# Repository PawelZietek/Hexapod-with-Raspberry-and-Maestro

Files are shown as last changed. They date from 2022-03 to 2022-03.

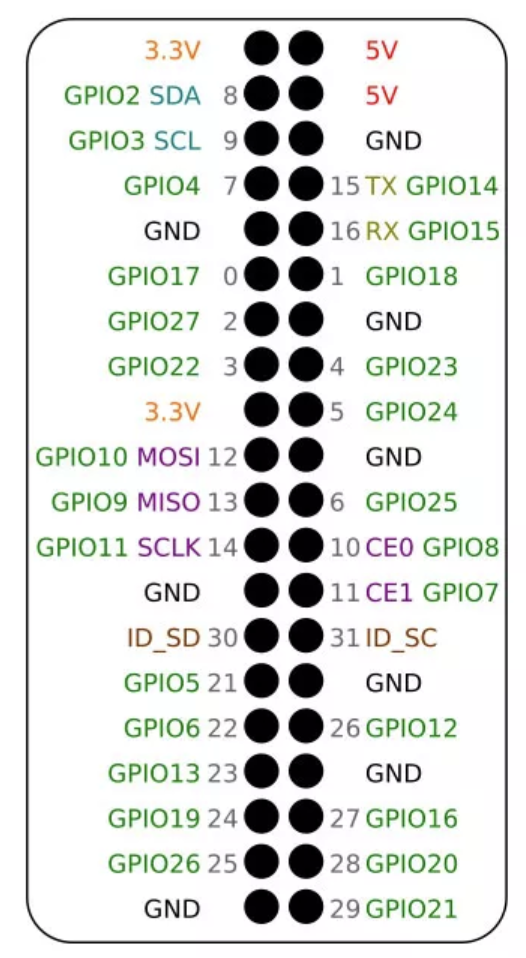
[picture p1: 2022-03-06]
pics, diagrams, videos/pinout.PNG

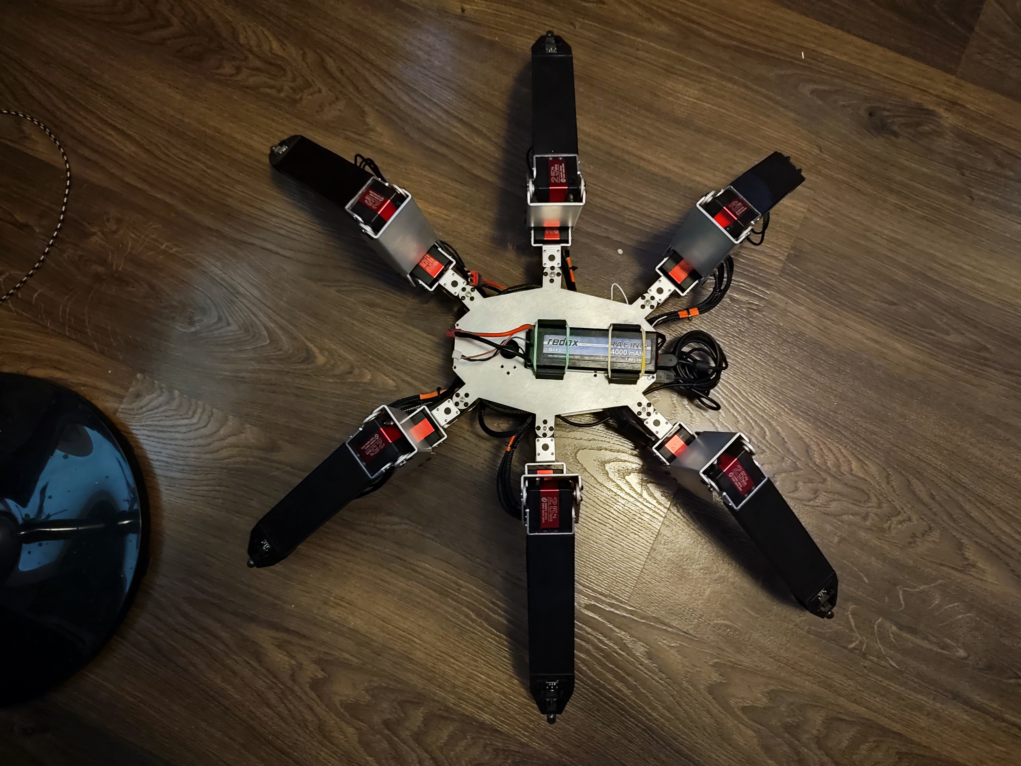
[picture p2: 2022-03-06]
pics, diagrams, videos/Hexapod4.jpg

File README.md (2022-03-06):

Hi, I built a hexapod based on a raspberry pi, pololu maestro 24 channel servo controller, 18x RDS3225 cheap robotics servos, and couple other stuff.
I share all needed files including 3d printed parts and dxf drawing for laser cutting. I also include pictures of all connections I've made.

The electronics you need(with links):
1. Raspberry Pi 4B 2GB - https://botland.store/raspberry-pi-4b-modules-and-kits/14646-raspberry-pi-4-model-b-wifi-dual-band-bluetooth-2gb-ram-15ghz-765756931175.html
2. Pololu Maestro 24ch - https://www.pololu.com/product/1356
3. 18x RDS3225 ROBOTIC servos - its important for servos to be robotic type with shafts on both sides - https://pl.aliexpress.com/item/32907625266.html?gatewayAdapt=glo2pol
4. UBEC 5V 3A - https://www.amazon.com/Adafruit-UBEC-Step-Down-Buck-Converter/dp/B00PLV0VC0
5. 6x microswitches - https://www.amazon.com/FYSETC-Printer-Accessories-Mechanical-Endstops/dp/B07ZCSXNF3
6. 2 cell 7,4V LiPo battery pack with charger
7. xbox 360 controller with usb receiver

Mechanical Parts and tools needed:
1. Screwdrivers, pliers, callipers
2. 3d printer access
3. cutting laser access
4. lots of m3, m4 phillips head screws different lenghts with washers and bolts
5. soldering iron access with wires and other stuff for it<br />

hexapod_project_fusion 1
hexapod_project_fusion 3
hexapod_project_fusion 4
Final models of leg and foot<br />
foot
leg

In the picture below i numbered servos from 0 to 17 and this is order i'm using later in my code.<br />
hexapod_project_fusion 6

Here's how i connected everything with raspberry.<br />
connection

And how swtiches and power are connected to Raspberry GPIO.<br />
gpio connection

My raspberry is using Ubuntu 20.04. Main code is in Python. You will need to instal repositories like xboxdrv, python3, pip, etc.<br />
Hexapod1
Hexapod2
Hexapod3
Hexapod4

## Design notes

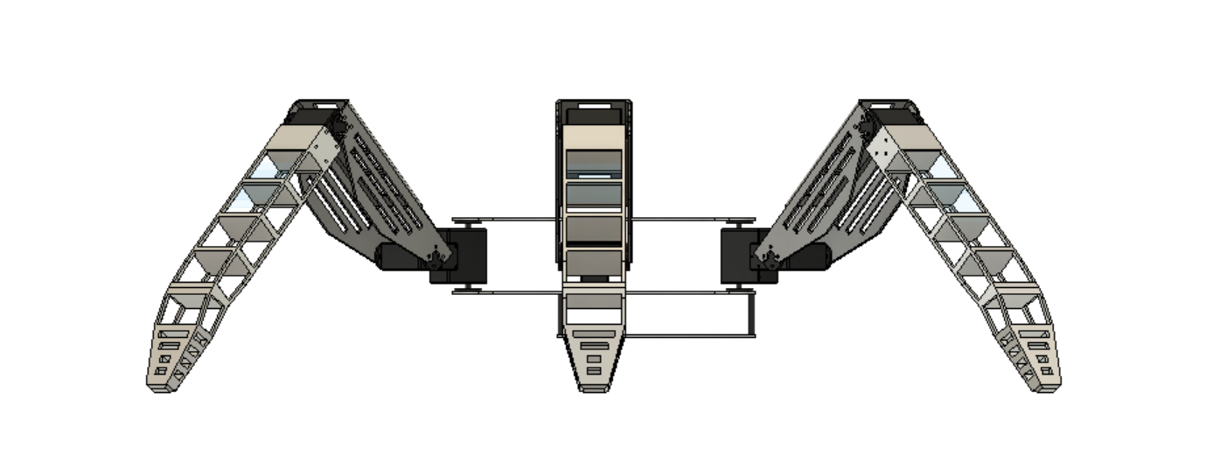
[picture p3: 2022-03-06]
pics, diagrams, videos/hexapod_project_fusion 2.PNG

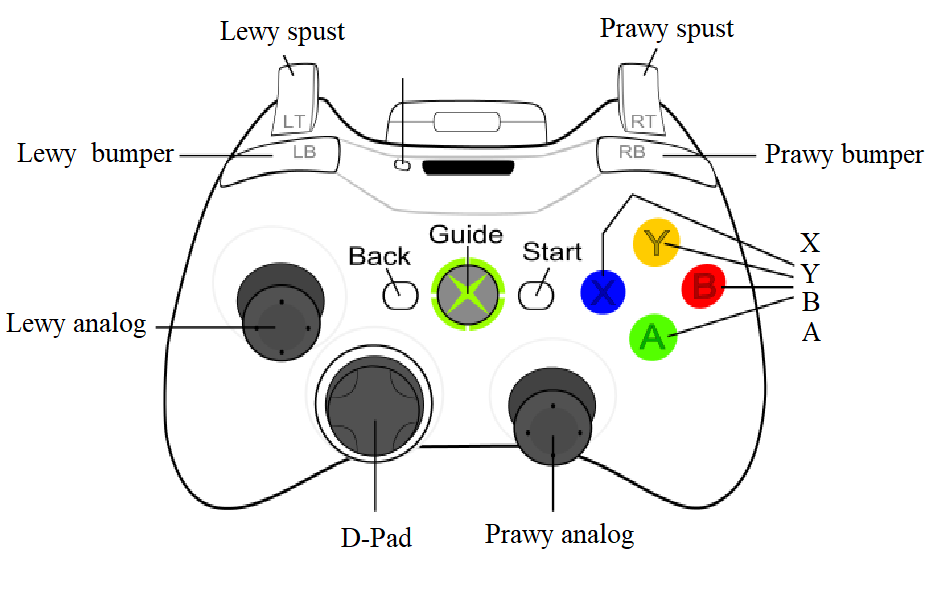
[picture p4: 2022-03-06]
pics, diagrams, videos/360_controller.png

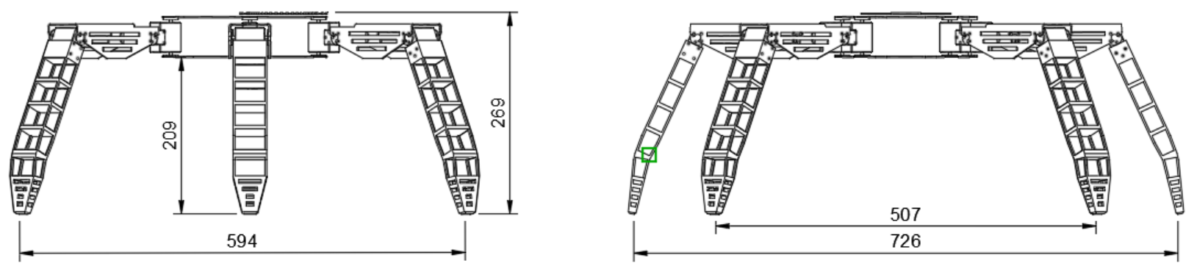
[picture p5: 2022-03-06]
pics, diagrams, videos/hexapod_drawings 2.PNG

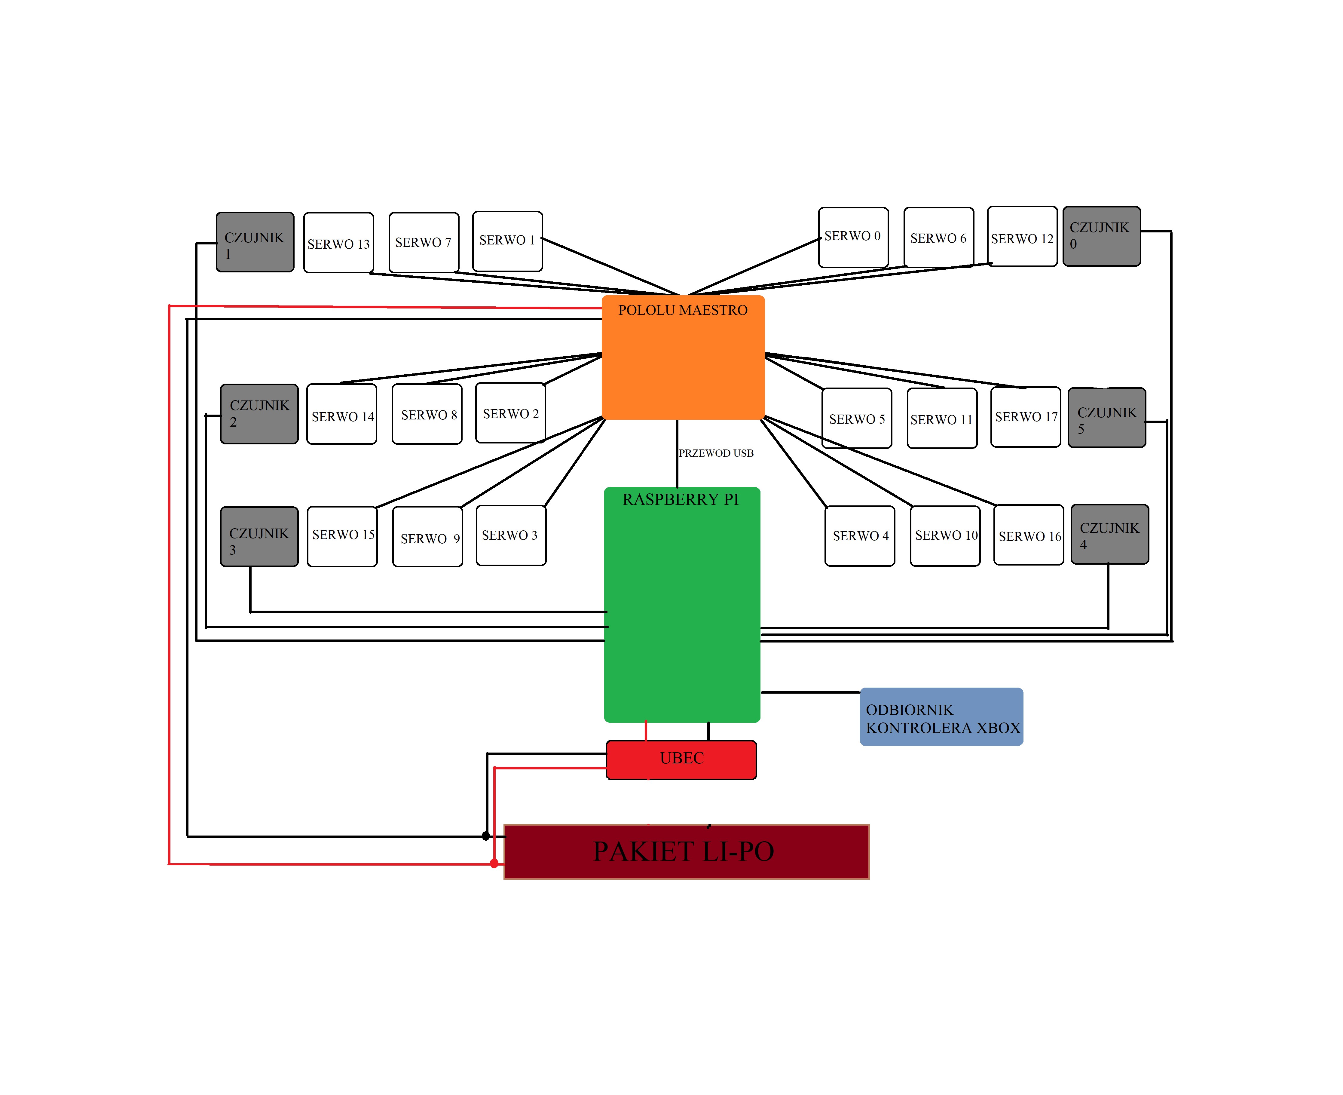
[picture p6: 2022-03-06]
pics, diagrams, videos/connection.png

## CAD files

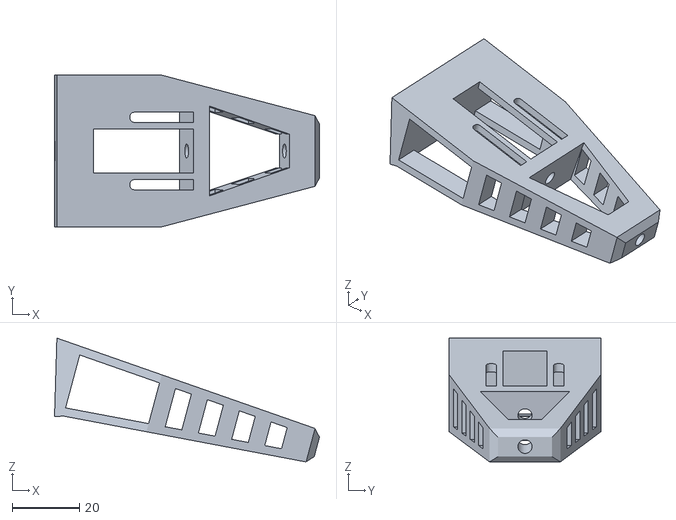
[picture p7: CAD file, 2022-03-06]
STL,dxf/foot.stl
78.6 x 45.0 x 36.7

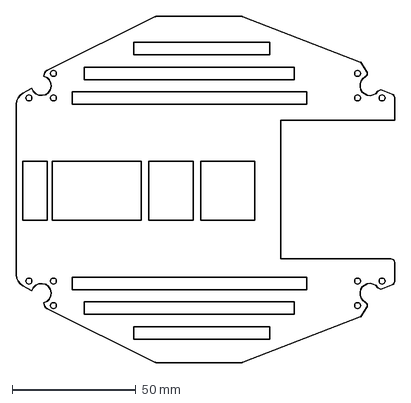
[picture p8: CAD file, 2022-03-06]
STL,dxf/tibia2018.dxf
153.0 x 140.0 mm

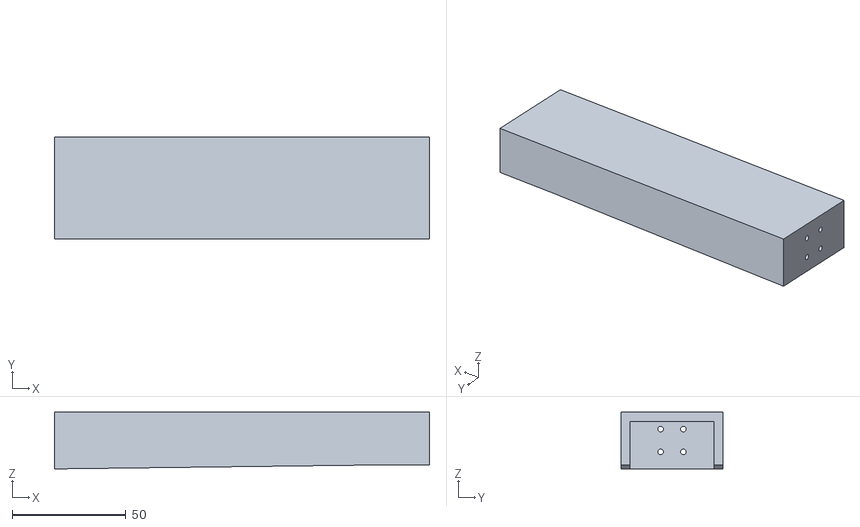
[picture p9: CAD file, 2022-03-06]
STL,dxf/Leg.stl
165.0 x 45.0 x 25.0

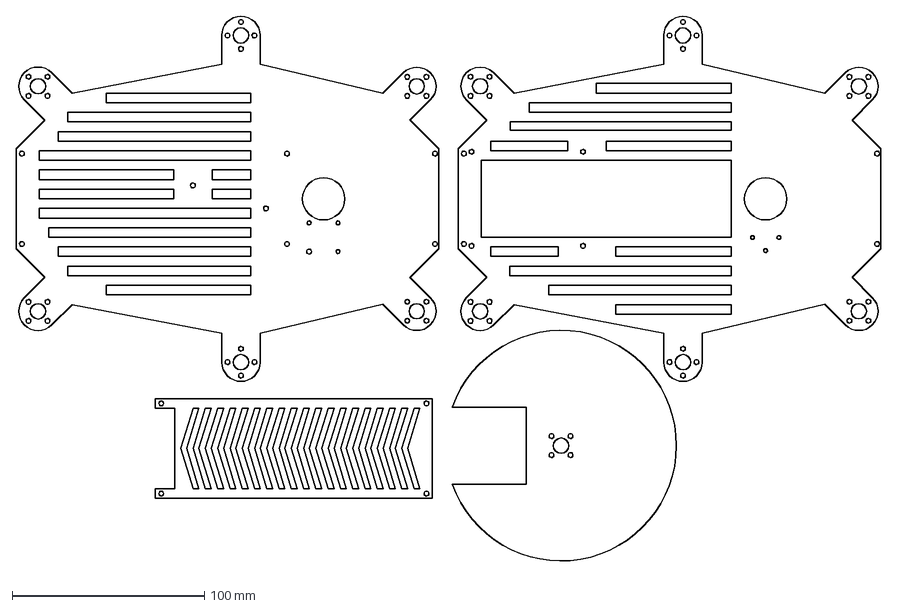
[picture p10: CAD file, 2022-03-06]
STL,dxf/Hexapod V2.dxf
450.0 x 287.5 mm

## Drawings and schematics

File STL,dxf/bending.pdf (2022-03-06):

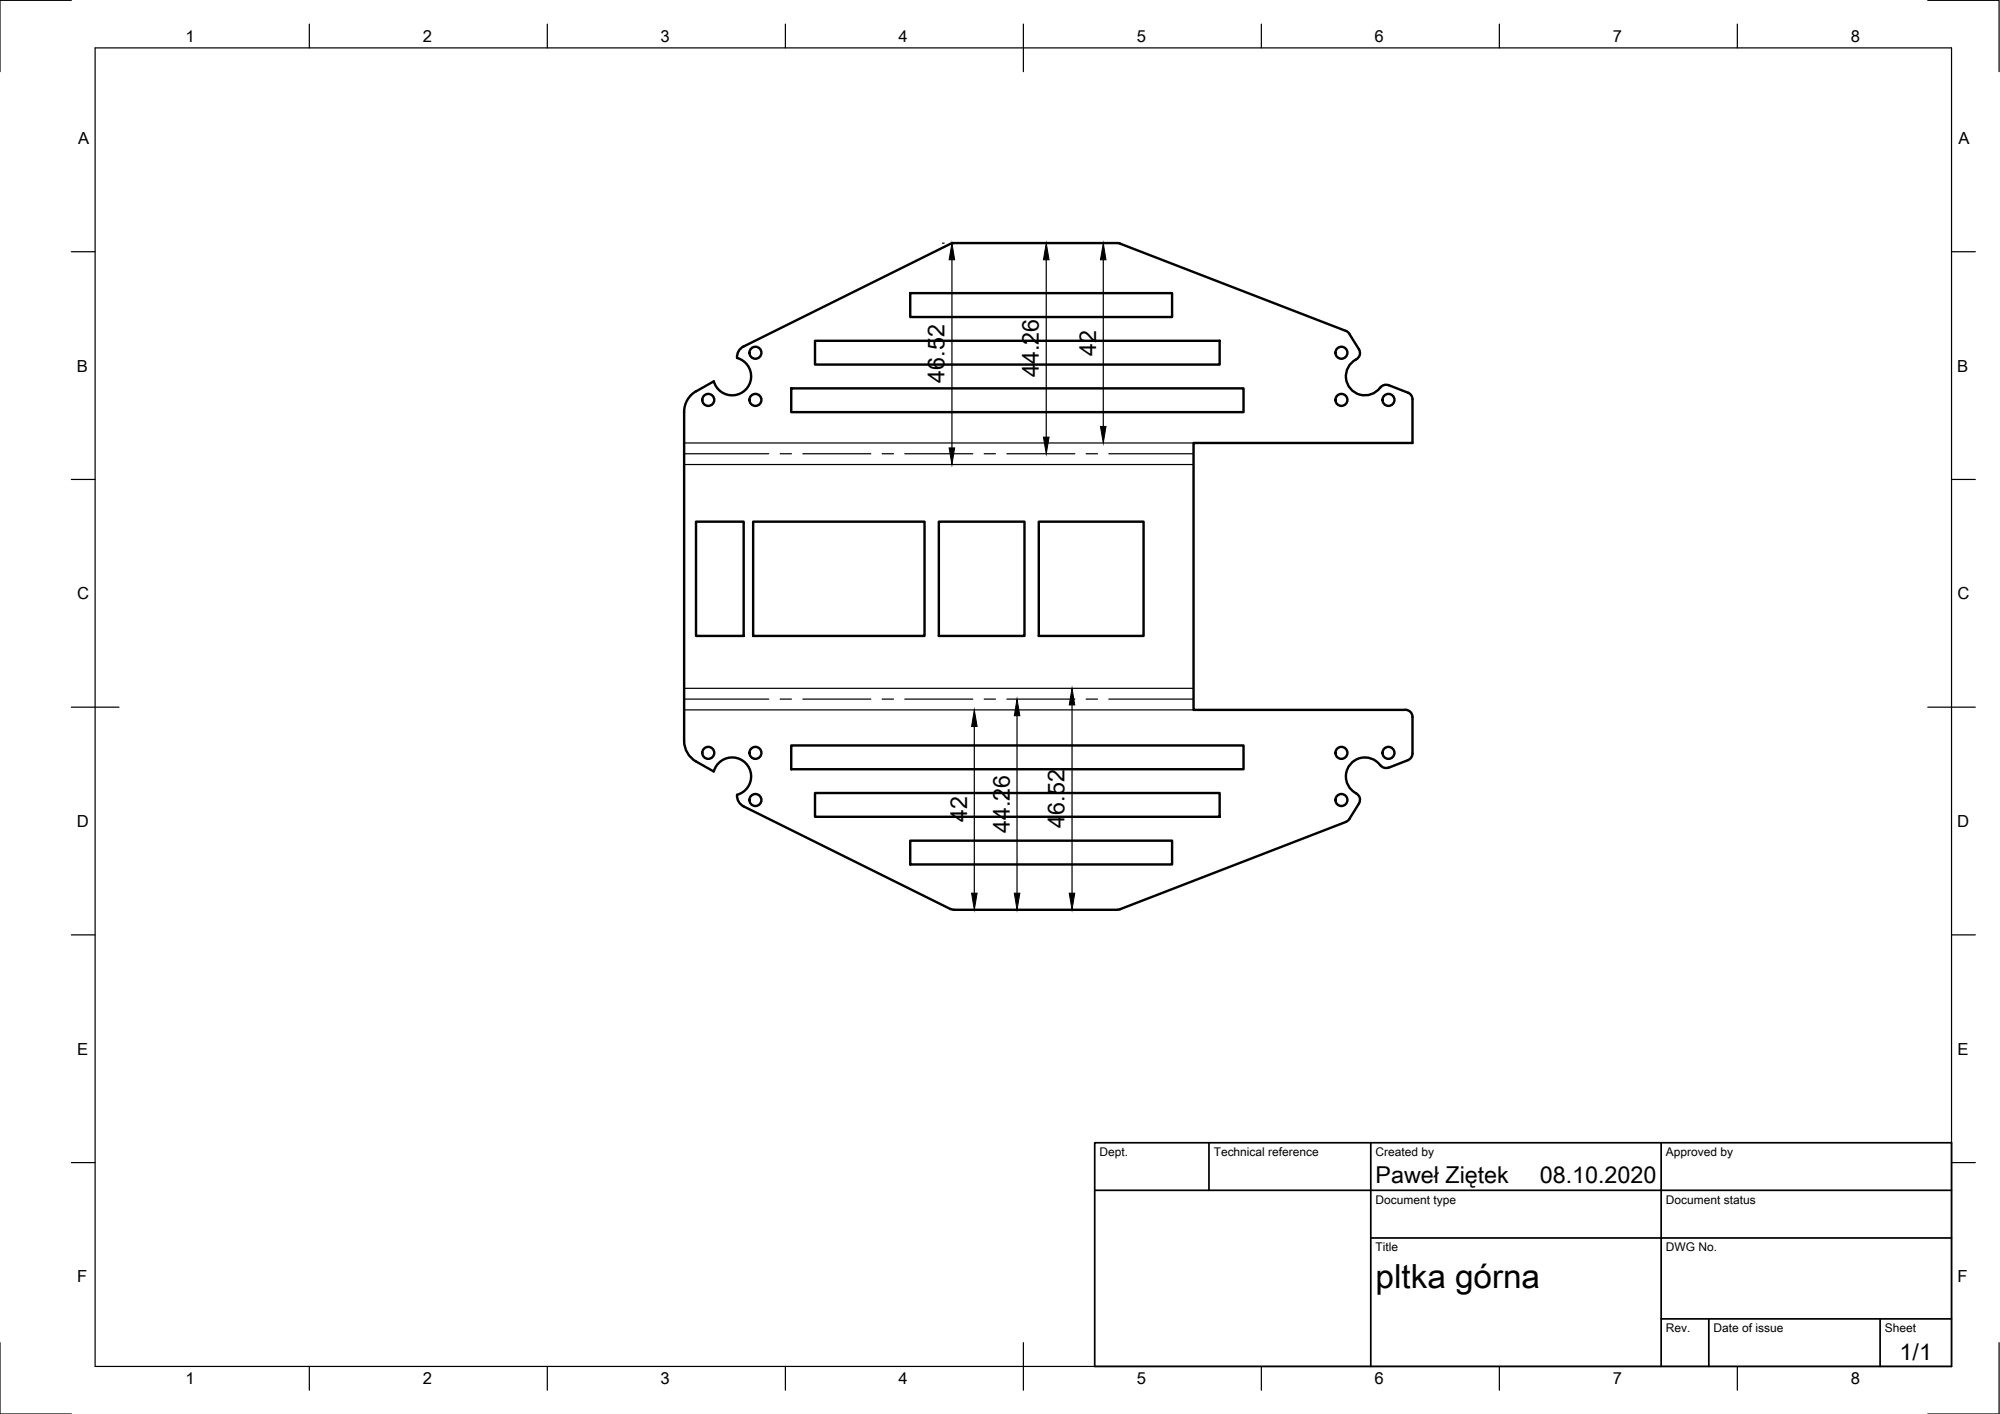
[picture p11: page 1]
Paweł Ziętek 42

Dept. | Technical reference | Created by 08.10.2020 | Approved by

Document type | Document status

Title pltka górna | DWG No.

Rev. | Date of issue | Sheet 1/1

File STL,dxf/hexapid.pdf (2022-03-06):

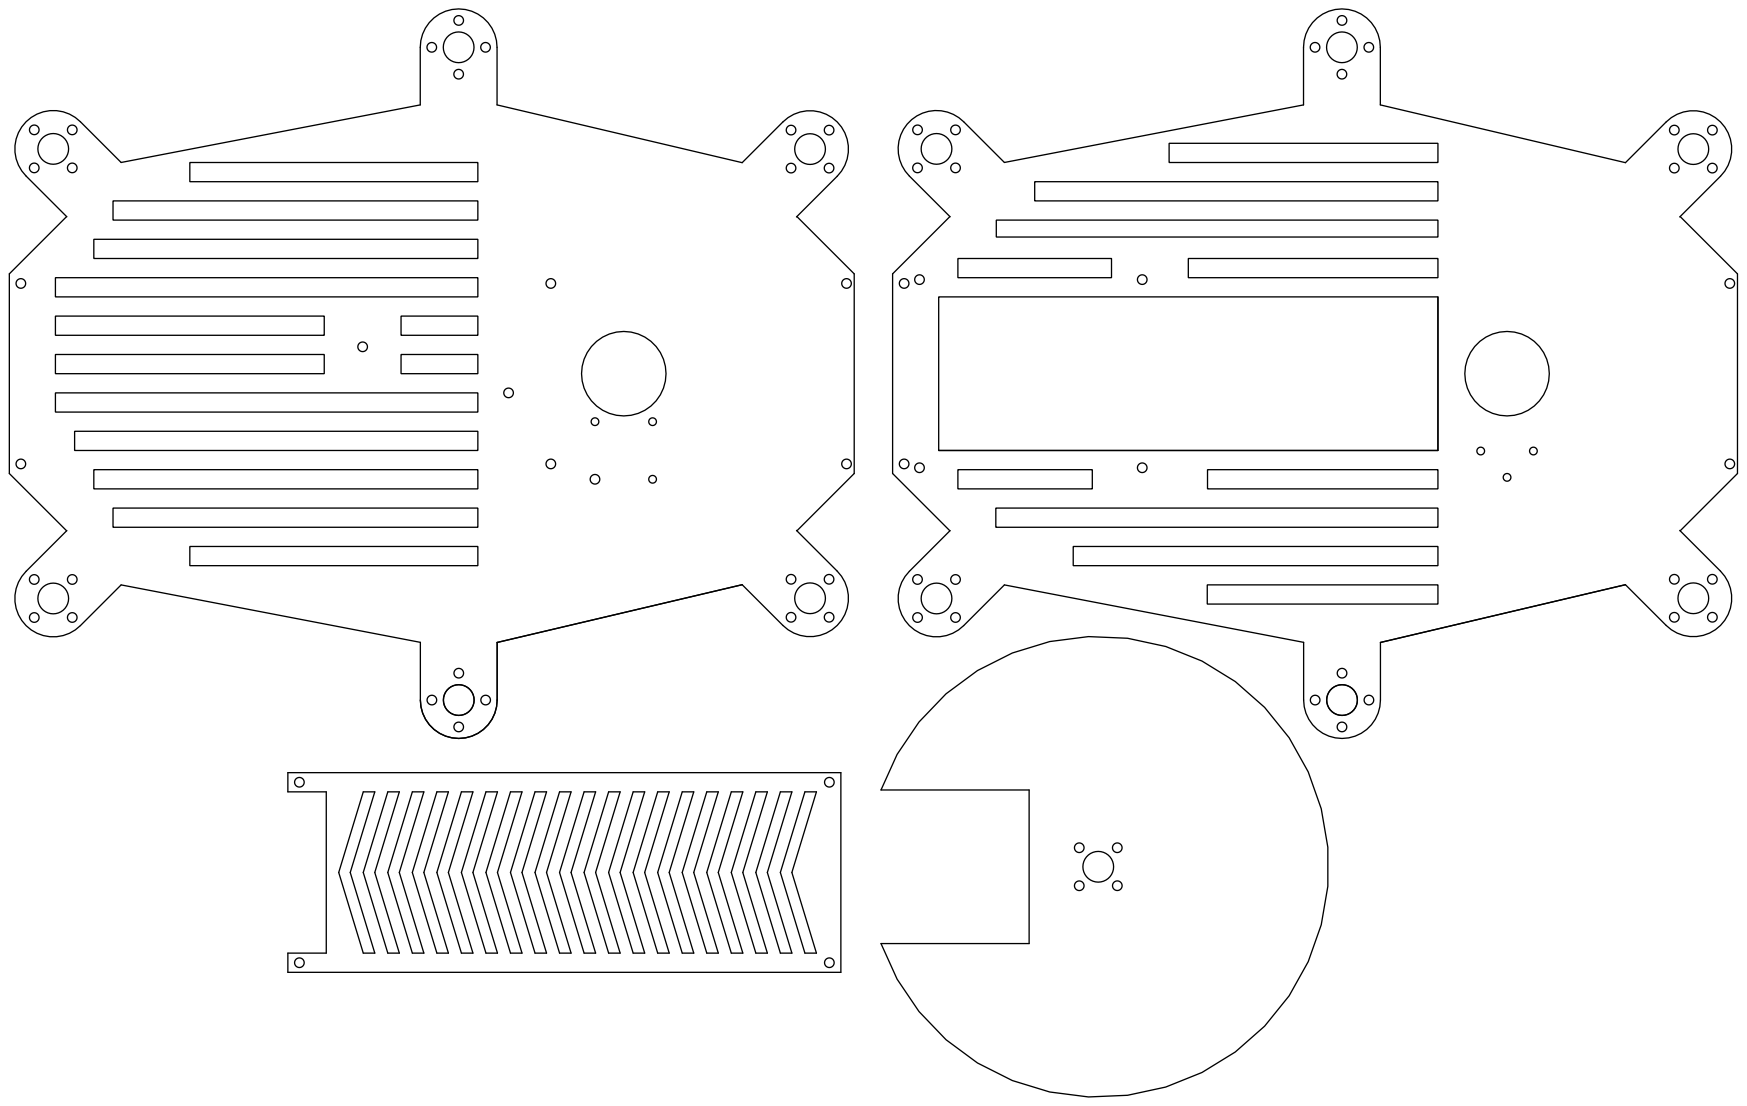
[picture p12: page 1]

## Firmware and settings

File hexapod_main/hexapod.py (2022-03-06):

import xbox
import maestro
import time
import math
import RPi.GPIO as GPIO


servo = maestro.Controller() #inicjalizacja sterownika maestro
joy = xbox.Joystick() #inicjacja kontrolera

#ustawienia numerowania GPIO
GPIO.setmode(GPIO.BCM)

#inicjalizacja przełączników krańcowych
GPIO.setup(16, GPIO.IN) #noga0
GPIO.setup(17, GPIO.IN) #noga1
GPIO.setup(27, GPIO.IN) #noga2
GPIO.setup(26, GPIO.IN) #noga3
GPIO.setup(20, GPIO.IN) #noga4
GPIO.setup(21, GPIO.IN) #noga5


#definicja zmiennych potrzebnych w dalszej części kodu
numer_nogi = 0
i = 0

#wyśrodkowanie wszystkich serwomechanizmów
servo.setTarget(6, 5500)
servo.setTarget(7, 5500)
servo.setTarget(8, 5500)
servo.setTarget(9, 5500)
servo.setTarget(10, 5200)
servo.setTarget(11, 5500)
time.sleep(1)
servo.setTarget(0, 6200)
servo.setTarget(1, 6000)
servo.setTarget(2, 5800)
servo.setTarget(3, 6900)
servo.setTarget(4, 5300)
servo.setTarget(5, 6200)
time.sleep(1)
servo.setTarget(12, 5000)
servo.setTarget(13, 5000)
servo.setTarget(14, 5000)
servo.setTarget(15, 5000)
servo.setTarget(16, 5000)
servo.setTarget(17, 5000)

#pętla ustawiająca przyśpieszenie i prędkość poruszania się serw
while i < 18:
	servo.setAccel(i, 0)
	servo.setSpeed(i, 100)
	i+=1
		
while not joy.Back(): 
#aby wyłączyć robota należy na kontrolerze wcisnąć przycisk "back"
		
	if joy.rightTrigger():	
	#Zwiększenie prześwitu robota poprzez wcisnięcie
	#prawego spustu kontrolera (im mocniej wciśnięty tym szybciej się podnosi)
	#im większą wartość zwróci joy.rightTrigger tym większą wartość dodana 
	#zostanie do wartości aktualnego położenia
		servo.setTarget(6, servo.getPosition(6)+int((joy.rightTrigger()*50)))
		servo.setTarget(7, servo.getPosition(7)+int((joy.rightTrigger()*50)))
		servo.setTarget(8, servo.getPosition(8)+int((joy.rightTrigger()*50)))
		servo.setTarget(9, servo.getPosition(9)+int((joy.rightTrigger()*50)))
		servo.setTarget(10, servo.getPosition(10)+int((joy.rightTrigger()*50)))
		servo.setTarget(11, servo.getPosition(11)+int((joy.rightTrigger()*50)))
		time.sleep(0.05)
	if joy.leftTrigger(): 
	#Zmiejszenie prześwitu robota poprzez wcisnięcie lewego spustu kontrolera 
	#(im mocniej wciśnięty tym szybciej się opuszcza)
	#dzialanie analogiczne do joy.rightTrigger lecz teraz odejmujemy 
	#określoną wartość od aktualnego położenia
		servo.setTarget(6, servo.getPosition(6)-int((joy.leftTrigger()*50)))
		servo.setTarget(7, servo.getPosition(7)-int((joy.leftTrigger()*50)))
		servo.setTarget(8, servo.getPosition(8)-int((joy.leftTrigger()*50)))
		servo.setTarget(9, servo.getPosition(9)-int((joy.leftTrigger()*50)))
		servo.setTarget(10, servo.getPosition(10)-int((joy.leftTrigger()*50)))
		servo.setTarget(11, servo.getPosition(11)-int((joy.leftTrigger()*50)))
		time.sleep(0.05)
	if joy.dpadRight(): #wychylenie robota w prawo
		servo.setTarget(0, servo.getPosition(0)+50)
		servo.setTarget(1, servo.getPosition(1)+50)
		servo.setTarget(2, servo.getPosition(2)+50)
		servo.setTarget(3, servo.getPosition(3)+50)
		servo.setTarget(4, servo.getPosition(4)+50)
		servo.setTarget(5, servo.getPosition(5)+50)
		time.sleep(0.05)
	if joy.dpadLeft(): #wychylenie robota w lewo
		servo.setTarget(0, servo.getPosition(0)-50)
		servo.setTarget(1, servo.getPosition(1)-50)
		servo.setTarget(2, servo.getPosition(2)-50)
		servo.setTarget(3, servo.getPosition(3)-50)
		servo.setTarget(4, servo.getPosition(4)-50)
		servo.setTarget(5, servo.getPosition(5)-50)
		time.sleep(0.05)
	if joy.dpadUp(): #podnoszenie piszczeli 
		servo.setTarget(12, servo.getPosition(12)+50)
		servo.setTarget(13, servo.getPosition(13)+50)
		servo.setTarget(14, servo.getPosition(14)+50)
		servo.setTarget(15, servo.getPosition(15)+50)
		servo.setTarget(16, servo.getPosition(16)+50)
		servo.setTarget(17, servo.getPosition(17)+50)
		time.sleep(0.05)
	if joy.dpadDown(): #opuszczanie piszczeli
		servo.setTarget(12, servo.getPosition(12)-50)
		servo.setTarget(13, servo.getPosition(13)-50)
		servo.setTarget(14, servo.getPosition(14)-50)
		servo.setTarget(15, servo.getPosition(15)-50)
		servo.setTarget(16, servo.getPosition(16)-50)
		servo.setTarget(17, servo.getPosition(17)-50)
		time.sleep(0.05)
	if joy.Start(): #przysisk start resetuje serwa robota do wartości początkowych (wyśrodkowuje serwa)
		servo.setTarget(6, 5500)
		servo.setTarget(7, 5500)
		servo.setTarget(8, 5500)
		servo.setTarget(9, 5500)
		servo.setTarget(10, 5300)
		servo.setTarget(11, 5500)
		time.sleep(1)
		servo.setTarget(0, 6200)
		servo.setTarget(1, 6000)
		servo.setTarget(2, 5800)
		servo.setTarget(3, 6900)
		servo.setTarget(4, 5300)
		servo.setTarget(5, 6200)
		time.sleep(1)
		servo.setTarget(12, 5000)
		servo.setTarget(13, 5000)
		servo.setTarget(14, 5000)
		servo.setTarget(15, 5000)
		servo.setTarget(16, 5000)
		servo.setTarget(17, 5000)
	if joy.rightX(deadzone=10000): #obrót hexapoda wokół własnej osi sterowane za pomocą wychylenia osi X prawego analoga kontrolera
		#podnosimy nogi 0, 2, 4 w górę o wartość 750
		servo.setTarget(6, servo.getPosition(6)-750)
		servo.setTarget(8, servo.getPosition(8)-750)
		servo.setTarget(10, servo.getPosition(10)-750)
		time.sleep(0.1)
		#Nogi 0, 2, 4 przesuwamy o wartość którą zmienia się wraz z wychyleniem gałki prawego analoga w osi X,
		#jeśli analog zwróci wartość mniejszą niż 0 to int((joy.right()*1000)) zwróci nam wartość ujemną,
		#a co za tym idzie do pozycji serw dodamy wartość, w drugim przypadku gdy int((joy.right()*1000)) będzie dodatnie,
		#to wtedy od pozycji serw odejmujemy okresloną wartość, a to determinuję w którą stronę obróci się robot.
		servo.setTarget(0,servo.getPosition(0)-int((joy.rightX()*1000)))
		servo.setTarget(2,servo.getPosition(2)-int((joy.rightX()*1000)))
		servo.setTarget(4,servo.getPosition(4)-int((joy.rightX()*1000)))
		time.sleep(0.1)
		#W tym kroku opuszczamy nogi 0, 2, 4 o wartość którą w kroku 1 je podnieśliśmy
		servo.setTarget(6, servo.getPosition(6)+750)
		servo.setTarget(8, servo.getPosition(8)+750)
		servo.setTarget(10, servo.getPosition(10)+750)
		time.sleep(0.3)
		#Powtórzenie tych samych operaacji na nogach 1, 3, 5
		servo.setTarget(7, servo.getPosition(7)-750)
		servo.setTarget(9, servo.getPosition(9)-750)
		servo.setTarget(11, servo.getPosition(11)-750)
		time.sleep(0.1)
		servo.setTarget(1,servo.getPosition(1)-int((joy.rightX()*1000)))
		servo.setTarget(3,servo.getPosition(3)-int((joy.rightX()*1000)))
		servo.setTarget(5,servo.getPosition(5)-int((joy.rightX()*1000)))
		time.sleep(0.1)
		servo.setTarget(7, servo.getPosition(7)+750)
		servo.setTarget(9, servo.getPosition(9)+750)
		servo.setTarget(11, servo.getPosition(11)+750)
		time.sleep(0.1)
		#Na końcu wyśrodkowujemy serwa 0, 1, 2 ,3 , 4, 5
		servo.setTarget(0, 6200)
		servo.setTarget(1, 6000)
		servo.setTarget(2, 5800)	
		servo.setTarget(3, 6900)
		servo.setTarget(4, 5300)
		servo.setTarget(5, 6200)
		time.sleep(0.2)
		
	if joy.leftY(deadzone=10000): #chodzenie do przodu oraz do tyłu sterowane za pomocą wychylenia w osi Y lewego analoga kontrolera
		servo.setTarget(7, servo.getPosition(6)-1000)
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

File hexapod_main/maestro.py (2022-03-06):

import serial
from sys import version_info

PY2 = version_info[0] == 2   #Running Python 2.x?

#
#---------------------------
# Maestro Servo Controller
#---------------------------
#
# Support for the Pololu Maestro line of servo controllers
#
# Steven Jacobs -- Aug 2013
# https://github.com/FRC4564/Maestro/
#
# These functions provide access to many of the Maestro's capabilities using the
# Pololu serial protocol
#
class Controller:
    # When connected via USB, the Maestro creates two virtual serial ports
    # /dev/ttyACM0 for commands and /dev/ttyACM1 for communications.
    # Be sure the Maestro is configured for "USB Dual Port" serial mode.
    # "USB Chained Mode" may work as well, but hasn't been tested.
    #
    # Pololu protocol allows for multiple Maestros to be connected to a single
    # serial port. Each connected device is then indexed by number.
    # This device number defaults to 0x0C (or 12 in decimal), which this module
    # assumes.  If two or more controllers are connected to different serial
    # ports, or you are using a Windows OS, you can provide the tty port.  For
    # example, '/dev/ttyACM2' or for Windows, something like 'COM3'.
    def __init__(self,ttyStr=('/dev/ttyACM0'),device=0x0c):
        # Open the command port
        self.usb = serial.Serial(ttyStr)
        # Command lead-in and device number are sent for each Pololu serial command.
        self.PololuCmd = chr(0xaa) + chr(device)
        # Track target position for each servo. The function isMoving() will
        # use the Target vs Current servo position to determine if movement is
        # occuring.  Upto 24 servos on a Maestro, (0-23). Targets start at 0.
        self.Targets = [0] * 24
        # Servo minimum and maximum targets can be restricted to protect components.
        self.Mins = [0] * 24
        self.Maxs = [0] * 24
        
    # Cleanup by closing USB serial port
    def close(self):
        self.usb.close()

    # Send a Pololu command out the serial port
    def sendCmd(self, cmd):
        cmdStr = self.PololuCmd + cmd
        if PY2:
            self.usb.write(cmdStr)
        else:
            self.usb.write(bytes(cmdStr,'latin-1'))

    # Set channels min and max value range.  Use this as a safety to protect
    # from accidentally moving outside known safe parameters. A setting of 0
    # allows unrestricted movement.
    #
    # ***Note that the Maestro itself is configured to limit the range of servo travel
    # which has precedence over these values.  Use the Maestro Control Center to configure
    # ranges that are saved to the controller.  Use setRange for software controllable ranges.
    def setRange(self, chan, min, max):
        self.Mins[chan] = min
        self.Maxs[chan] = max

    # Return Minimum channel range value
    def getMin(self, chan):
        return self.Mins[chan]

    # Return Maximum channel range value
    def getMax(self, chan):
        return self.Maxs[chan]
        
    # Set channel to a specified target value.  Servo will begin moving based
    # on Speed and Acceleration parameters previously set.
    # Target values will be constrained within Min and Max range, if set.
    # For servos, target represents the pulse width in of quarter-microseconds
    # Servo center is at 1500 microseconds, or 6000 quarter-microseconds
    # Typcially valid servo range is 3000 to 9000 quarter-microseconds
    # If channel is configured for digital output, values < 6000 = Low ouput
    def setTarget(self, chan, target):
        # if Min is defined and Target is below, force to Min
        if self.Mins[chan] > 0 and target < self.Mins[chan]:
            target = self.Mins[chan]
        # if Max is defined and Target is above, force to Max
        if self.Maxs[chan] > 0 and target > self.Maxs[chan]:
            target = self.Maxs[chan]
        #    
        lsb = target & 0x7f #7 bits for least significant byte
        msb = (target >> 7) & 0x7f #shift 7 and take next 7 bits for msb
        cmd = chr(0x04) + chr(chan) + chr(lsb) + chr(msb)
        self.sendCmd(cmd)
        # Record Target value
        self.Targets[chan] = target
        
    # Set speed of channel
    # Speed is measured as 0.25microseconds/10milliseconds
    # For the standard 1ms pulse width change to move a servo between extremes, a speed
    # of 1 will take 1 minute, and a speed of 60 would take 1 second.
    # Speed of 0 is unrestricted.
    def setSpeed(self, chan, speed):
        lsb = speed & 0x7f #7 bits for least significant byte
        msb = (speed >> 7) & 0x7f #shift 7 and take next 7 bits for msb
        cmd = chr(0x07) + chr(chan) + chr(lsb) + chr(msb)
        self.sendCmd(cmd)

    # Set acceleration of channel
    # This provide soft starts and finishes when servo moves to target position.
    # Valid values are from 0 to 255. 0=unrestricted, 1 is slowest start.
    # A value of 1 will take the servo about 3s to move between 1ms to 2ms range.
    def setAccel(self, chan, accel):
        lsb = accel & 0x7f #7 bits for least significant byte
        msb = (accel >> 7) & 0x7f #shift 7 and take next 7 bits for msb
        cmd = chr(0x09) + chr(chan) + chr(lsb) + chr(msb)
        self.sendCmd(cmd)
    
    # Get the current position of the device on the specified channel
    # The result is returned in a measure of quarter-microseconds, which mirrors
    # the Target parameter of setTarget.
    # This is not reading the true servo position, but the last target position sent
    # to the servo. If the Speed is set to below the top speed of the servo, then
    # the position result will align well with the acutal servo position, assuming
    # it is not stalled or slowed.
    def getPosition(self, chan):
        cmd = chr(0x10) + chr(chan)
        self.sendCmd(cmd)
        lsb = ord(self.usb.read())
        msb = ord(self.usb.read())
        return (msb << 8) + lsb

    # Test to see if a servo has reached the set target position.  This only provides
    # useful results if the Speed parameter is set slower than the maximum speed of
    # the servo.  Servo range must be defined first using setRange. See setRange comment.
    #
    # ***Note if target position goes outside of Maestro's allowable range for the
    # channel, then the target can never be reached, so it will appear to always be
    # moving to the target.  
    def isMoving(self, chan):
        if self.Targets[chan] > 0:
            if self.getPosition(chan) != self.Targets[chan]:
                return True
        return False
    
    # Have all servo outputs reached their targets? This is useful only if Speed and/or
    # Acceleration have been set on one or more of the channels. Returns True or False.
    # Not available with Micro Maestro.
    def getMovingState(self):
        cmd = chr(0x13)
        self.sendCmd(cmd)
        if self.usb.read() == chr(0):
            return False
        else:
            return True
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
